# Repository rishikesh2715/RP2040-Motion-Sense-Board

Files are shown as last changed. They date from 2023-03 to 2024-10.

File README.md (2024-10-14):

# AN updated version of this board is available [here](https://github.com/rishikesh2715/RP2040_Motion_Logger)

# RP2040-Motion-Sense-Board

A microcontroller PCB based on the RP2040 MCU from Raspberry Pi with an on-board high-performance IMU, 2S LiPo battery charging circuit, 32 MB quad SPI flash memory, and a bunch of GPIO breakouts.

## Features

- ICM 42688-P IMU
- 2S LiPo battery charging circuit
- 32 MB quad SPI flash memory
- TC2030 debug port
- USB C
- ESD protection circuit
- RGB LED
- Multilple GPIO breakouts
- 1 I2C
- 4 ADC
- 1 UART

## Disclaimer

I have not personally tested this board. If you want to manufacture it, you should carefully go through the design once. Downloading this project and opening it in KiCad and running the ERC or DRC will result in many warnings, but almost all of them are safe to ignore as most of them are courtyard overlapping warnings.

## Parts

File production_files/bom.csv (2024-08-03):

Designator | Footprint | Quantity | Value | LCSC Part #
SW2 | SW_SPST_B3U-1000P | 1 | SW_SPST
Y1 | Crystal_SMD_3225-4Pin_3.2x2.5mm | 1 | 12MHz
J3 | PinSocket_1x20_P2.54mm_Vertical | 1 | Conn_01x20
D1 | D_1206_3216Metric | 1 | D_Schottky_Small
C22 | C_0402_1005Metric | 1 | 100n
C18 | C_0402_1005Metric | 1 | 100n
C30 | C_0402_1005Metric | 1 | 1u
C8 | C_0402_1005Metric | 1 | 100n
C29 | C_0402_1005Metric | 1 | 1u
J1 | JST_PH_S2B-PH-SM4-TB_1x02-1MP_P2.00mm_Horizontal | 1 | JST-PH
C24 | C_0402_1005Metric | 1 | 100n
C27 | C_0402_1005Metric | 1 | 10n
D5 | LED_0603_1608Metric | 1 | Green
Q1 | TSOT-23 | 1 | TP0610L
U4 | ICP-42688-P | 1 | ICM-42688-P
C33 | C_0402_1005Metric | 1 | 1u
C6 | C_0402_1005Metric | 1 | 10p
R10 | R_0603_1608Metric | 1 | 37K4
U3 | W25Q64JVXGIQ_TR | 1 | W25Q32JVZP
R13 | R_0402_1005Metric | 1 | 4k7
R6 | R_0402_1005Metric | 1 | 27R
R5 | R_0402_1005Metric | 1 | 5k1
C11 | C_0402_1005Metric | 1 | 100n
R12 | R_0402_1005Metric | 1 | 4K7
C19 | C_0402_1005Metric | 1 | 100n
J4 | PinHeader_1x14_P2.54mm_Vertical | 1 | Conn_01x14
R3 | R_0402_1005Metric | 1 | 4K7
C7 | C_0402_1005Metric | 1 | 100n
C32 | C_0402_1005Metric | 1 | 1u
FB1 | R_0402_1005Metric | 1 | 480R@100MHz
D7 | LED_SK6805_PLCC4_2.4x2.7mm_P1.3mm | 1 | SK6805
R9 | R_0603_1608Metric | 1 | 118K
R15 | R_0402_1005Metric | 1 | 4K7
C9 | C_0402_1005Metric | 1 | 4u7
C21 | C_0402_1005Metric | 1 | 100n
C14 | C_0402_1005Metric | 1 | 100n
R4 | R_0402_1005Metric | 1 | 5k1
C28 | C_0402_1005Metric | 1 | 1u
D4 | SOT-143 | 1 | PRTR5V0U2X
C10 | C_0402_1005Metric | 1 | 100n
R1 | R_0603_1608Metric | 1 | 10K
R7 | R_0402_1005Metric | 1 | 27R
R16 | R_0402_1005Metric | 1 | 4K7
R11 | R_0402_1005Metric | 1 | 1K
C3 | C_0805_2012Metric | 1 | 10u
C2 | C_0805_2012Metric | 1 | 10u
C1 | C_0805_2012Metric | 1 | 10u
R8 | R_0402_1005Metric | 1 | 5K
U2 | QFN40P700X700X90-57N | 1 | RP2040
D3 | LED_0603_1608Metric | 1 | Green
C23 | C_0402_1005Metric | 1 | 1u
C4 | C_0402_1005Metric | 1 | 10p
C12 | C_0402_1005Metric | 1 | 100n
D6 | LED_0603_1608Metric | 1 | LED
C16 | C_0402_1005Metric | 1 | 100n
C20 | C_0402_1005Metric | 1 | 1u
J5 | JST_SH_SM04B-SRSS-TB_1x04-1MP_P1.00mm_Horizontal | 1 | Conn_01x04
J6 | JST_SH_SM04B-SRSS-TB_1x04-1MP_P1.00mm_Horizontal | 1 | Conn_01x04
D2 | LED_0603_1608Metric | 1 | Orange
C31 | C_0402_1005Metric | 1 | 1u
IC1 | MAX17626ATA+T | 1 | MAX17626ATA+T
C25 | C_0402_1005Metric | 1 | 0.1u
P1 | USB_C_Receptacle_HRO_TYPE-C-31-M-12 | 1 | USB_C_Plug_USB2.0
C26 | C_0603_1608Metric | 1 | 2u2
SW1 | SW_SPST_B3U-1000P | 1 | RESET
R2 | R_0402_1005Metric | 1 | 4K7
C5 | C_0805_2012Metric | 1 | 10u
J2 | Tag-Connect_TC2030-IDC-NL_2x03_P1.27mm_Vertical | 1 | TC2030-IDC-NL
R17 | R_0402_1005Metric | 1 | 4K7
R14 | R_0402_1005Metric | 1 | 4K7
U1 | SOT-23-5 | 1 | MCP73831-2-OT
C13 | C_0402_1005Metric | 1 | 10u
L1 | L_1008_2520Metric | 1 | 1u

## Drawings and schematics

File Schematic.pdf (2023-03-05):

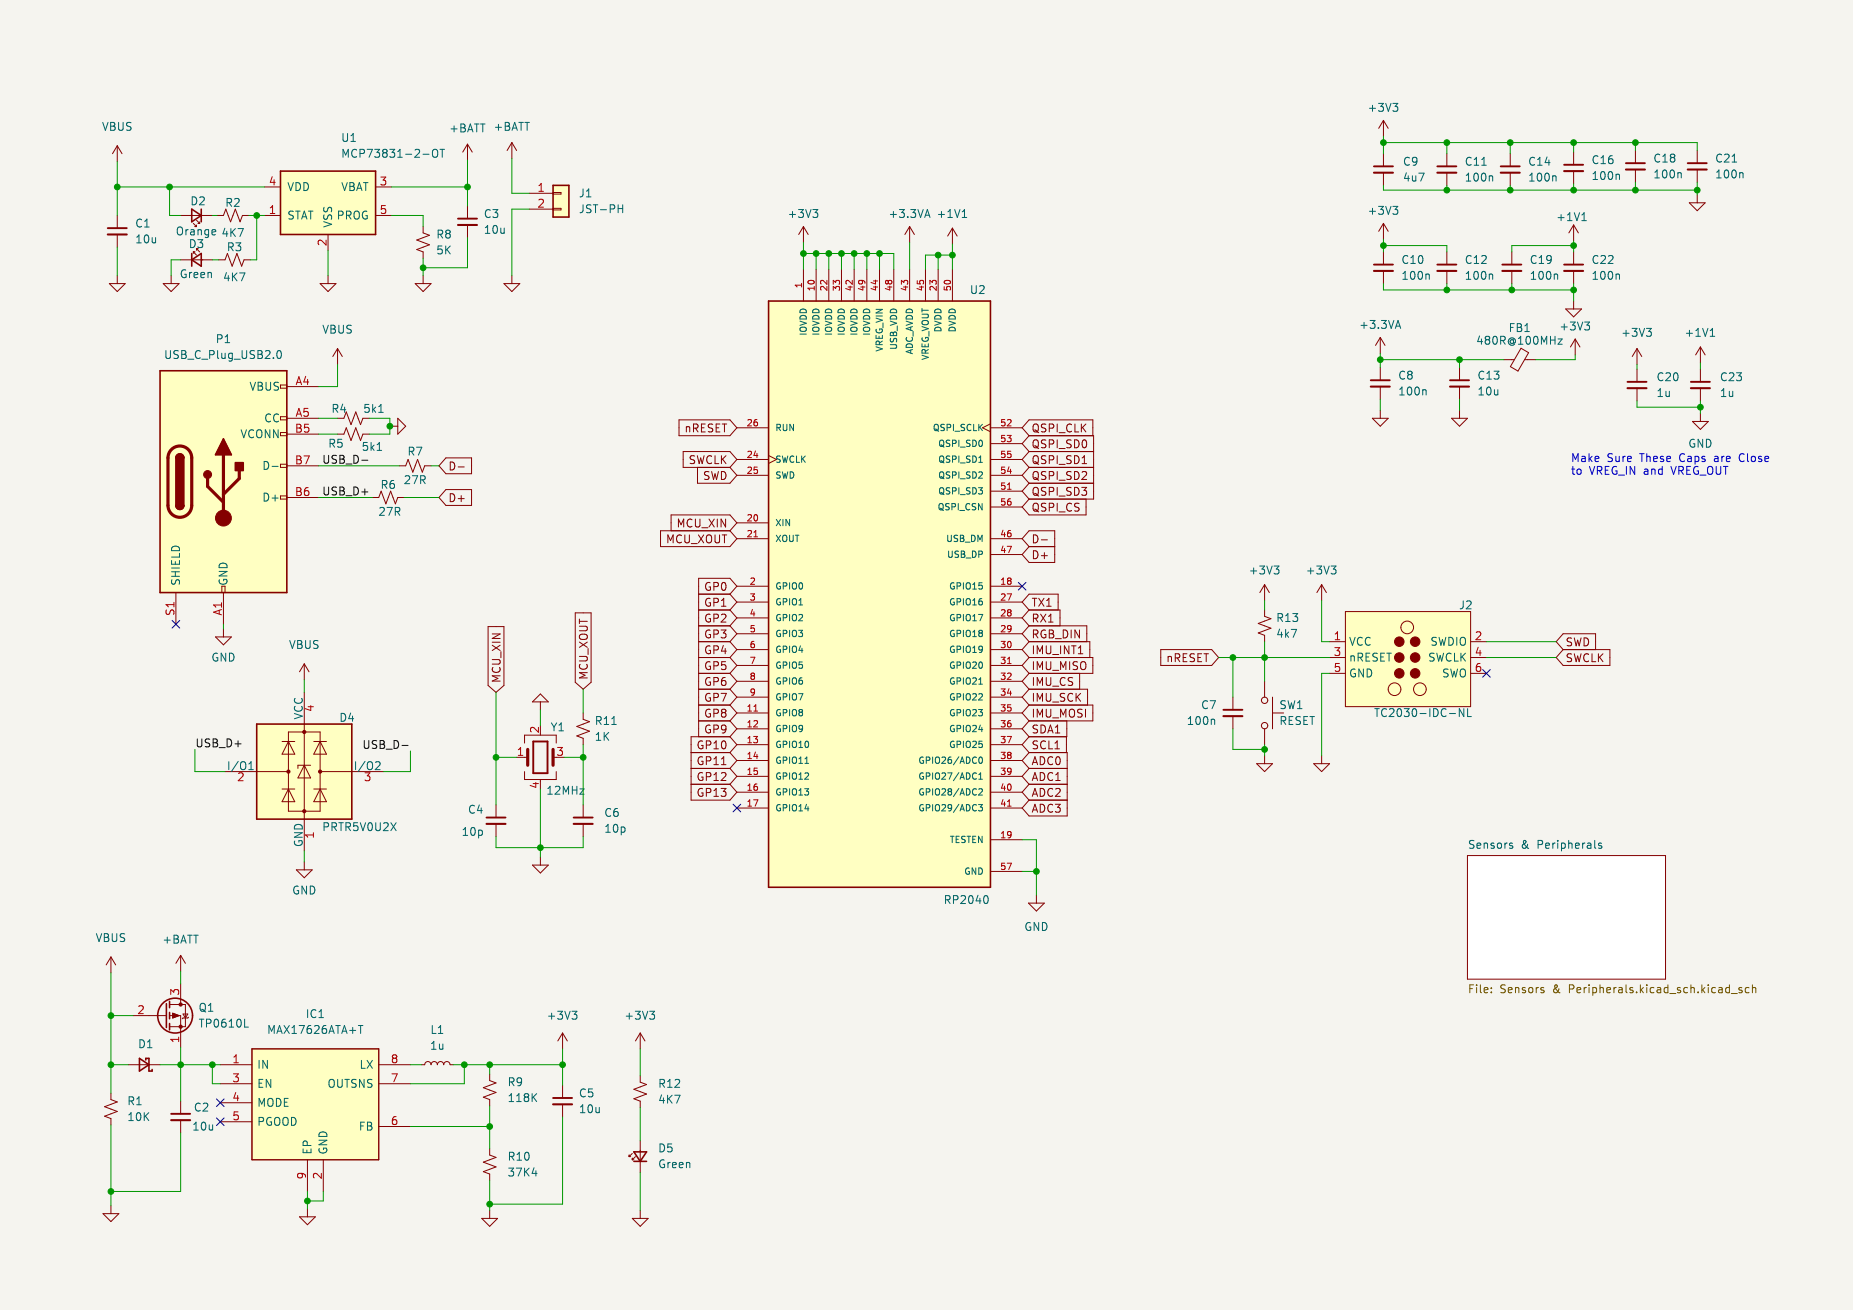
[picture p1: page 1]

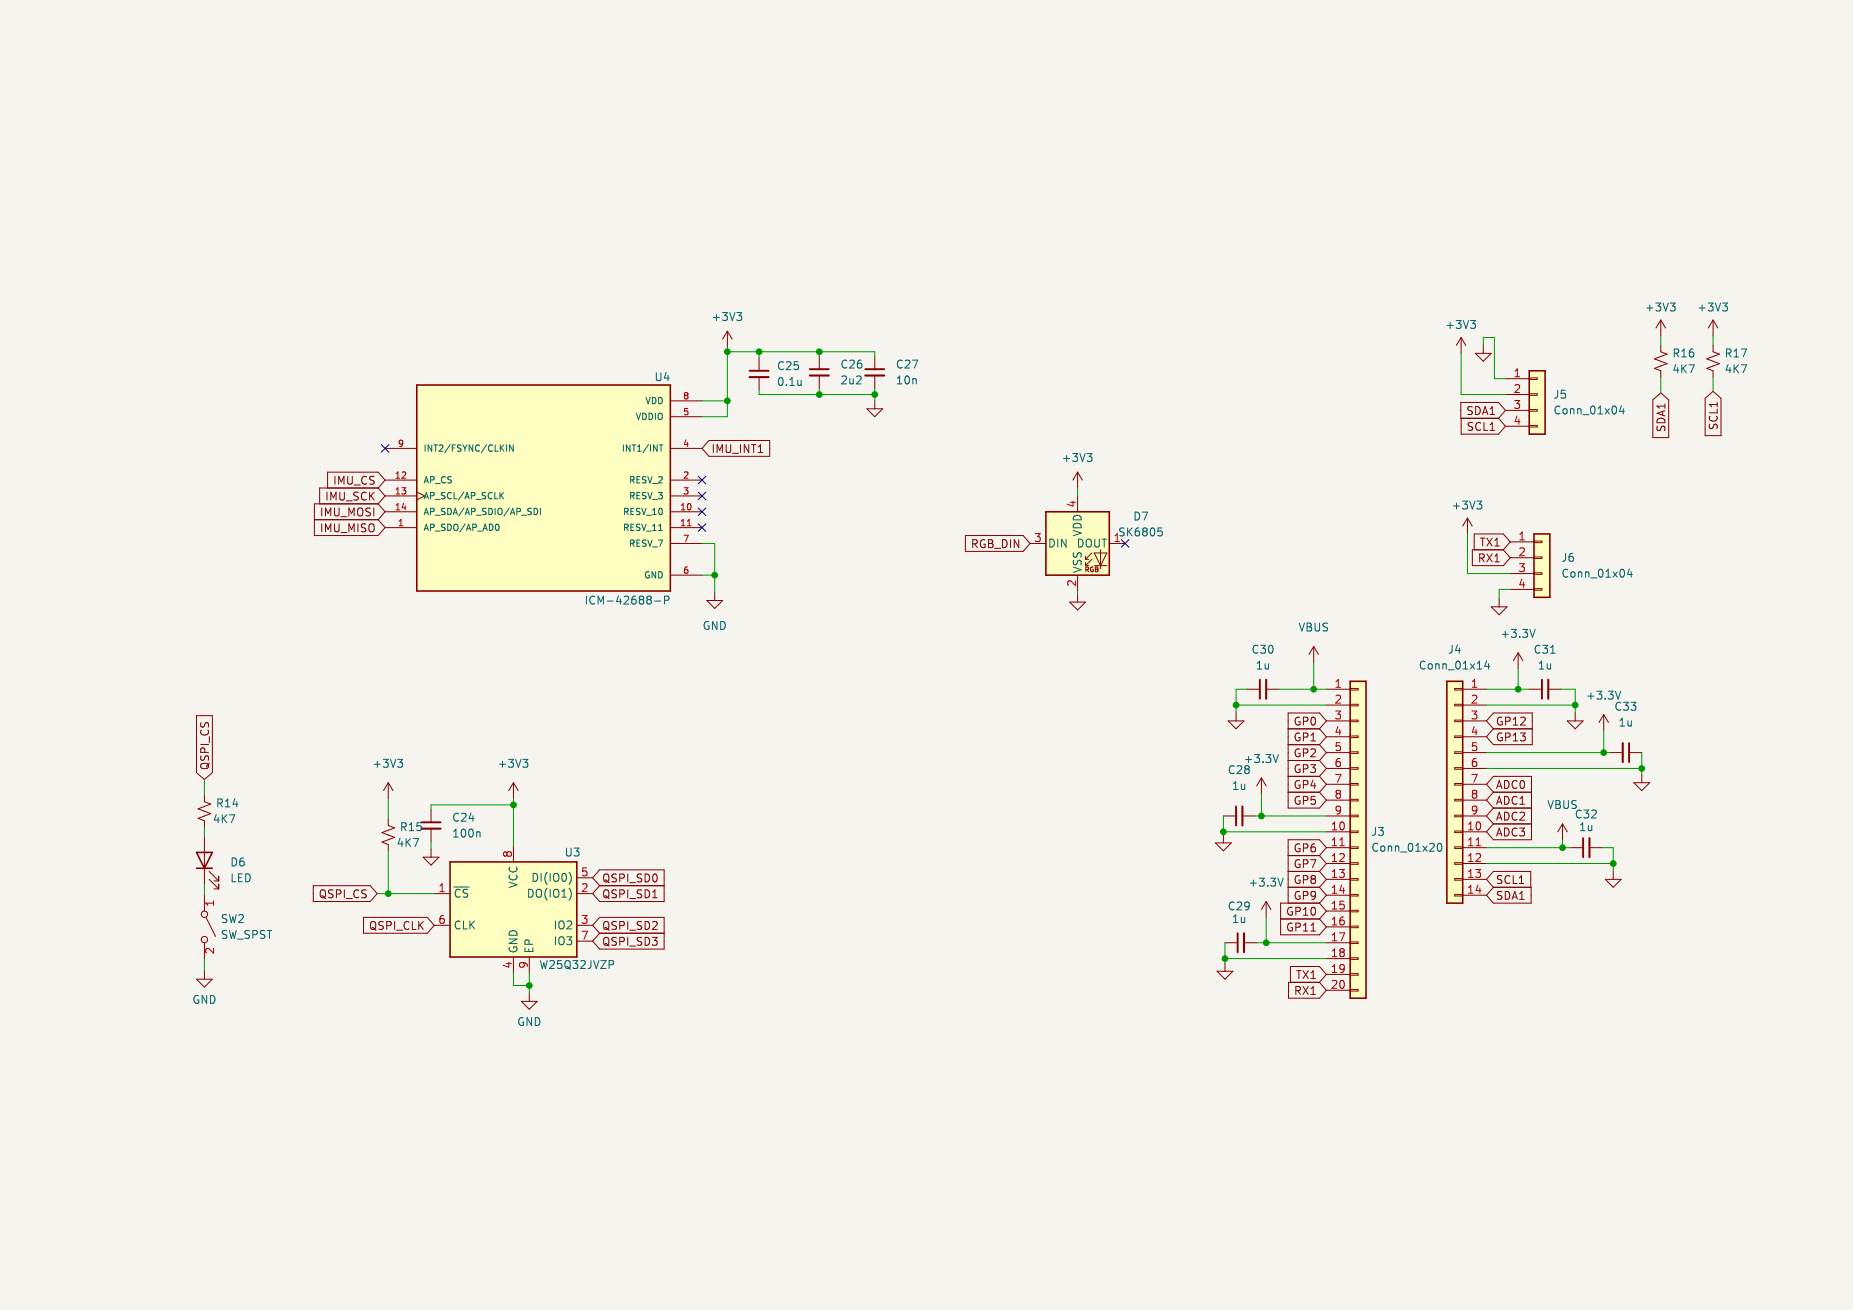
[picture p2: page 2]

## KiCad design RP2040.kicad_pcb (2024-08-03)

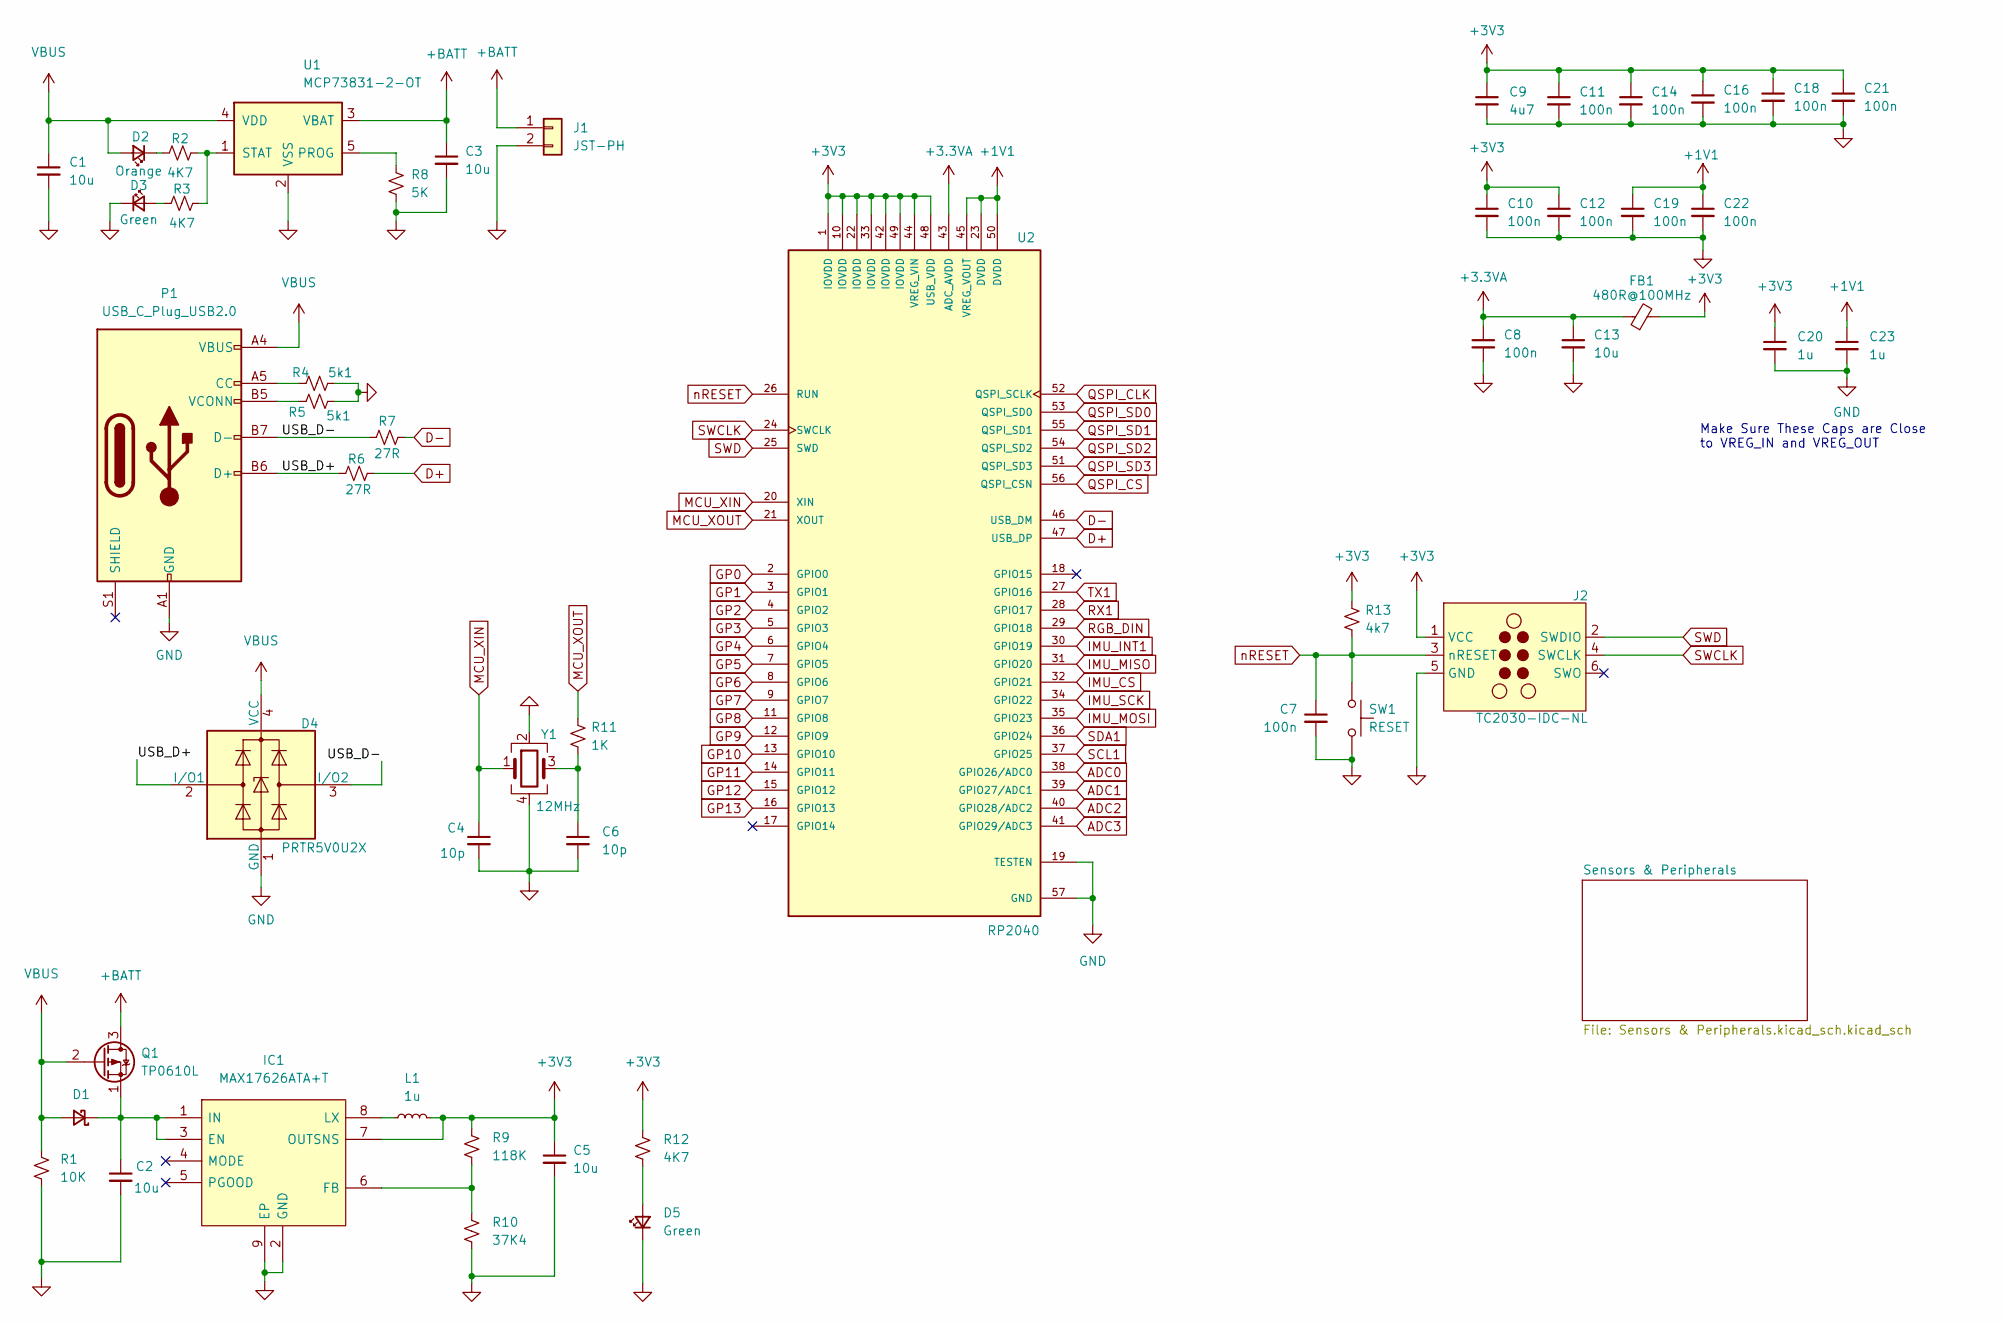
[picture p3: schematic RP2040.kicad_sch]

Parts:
C1, C2, C3, C5: 10u; C_0805_2012Metric
C4, C6: 10p; C_0402_1005Metric
C7, C8, C10, C11, C12, C14, C16, C18, C19, C21, C22: 100n; C_0402_1005Metric
C9: 4u7; C_0402_1005Metric
C13: 10u; C_0402_1005Metric
C20, C23: 1u; C_0402_1005Metric
D1: D_Schottky_Small; D_1206_3216Metric
D2: Orange; LED_0603_1608Metric
D3, D5: Green; LED_0603_1608Metric
D4: PRTR5V0U2X; SOT-143
FB1: 480R@100MHz; R_0402_1005Metric
IC1: MAX17626ATA+T; Mouser Part Number 700-MAX17626ATA+T
J1: JST-PH; JST_PH_S2B-PH-SM4-TB_1x02-1MP_P2.00mm_Horizontal
J2: TC2030-IDC-NL; Tag-Connect_TC2030-IDC-NL_2x03_P1.27mm_Vertical
L1: 1u; L_1008_2520Metric
P1: USB_C_Plug_USB2.0; USB_C_Receptacle_HRO_TYPE-C-31-M-12
Q1: TP0610L; TSOT-23
R1: 10K; R_0603_1608Metric
R2, R3, R12: 4K7; R_0402_1005Metric
R4, R5: 5k1; R_0402_1005Metric
R6, R7: 27R; R_0402_1005Metric
R8: 5K; R_0402_1005Metric
R9: 118K; R_0603_1608Metric
R10: 37K4; R_0603_1608Metric
R11: 1K; R_0402_1005Metric
R13: 4k7; R_0402_1005Metric
SW1: RESET; SW_SPST_B3U-1000P
U1: MCP73831-2-OT; SOT-23-5
U2: RP2040; QFN40P700X700X90-57N; PARTREV 1.6.1
Y1: 12MHz; Crystal_SMD_3225-4Pin_3.2x2.5mm

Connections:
+1V1: C19.1, C22.1, C23.1, U2.23 (DVDD), U2.45 (VREG_VOUT), U2.50 (DVDD)
+3.3VA: C8.1, C13.1, FB1.1, U2.43 (ADC_AVDD)
+3V3: C5.1, C9.1, C10.1, C11.1, C12.1, C14.1, C16.1, C18.1, C20.1, C21.1, FB1.2, IC1.7 (OUTSNS), J2.1 (VCC), L1.2, R9.1, R12.1, R13.1, U2.1 (IOVDD), U2.10 (IOVDD), U2.22 (IOVDD), U2.33 (IOVDD), U2.42 (IOVDD), U2.44 (VREG_VIN), U2.48 (USB_VDD), U2.49 (IOVDD); also elsewhere on the board
+BATT: C3.1, J1.1, Q1.3 (D), U1.3 (VBAT)
/USB_D+: D4.2 (I/O1), P1.B6 (D+), R6.1
/USB_D-: D4.3 (I/O2), P1.B7 (D-), R7.1
ADC0: U2.38 (GPIO26/ADC0); also elsewhere on the board
ADC1: U2.39 (GPIO27/ADC1); also elsewhere on the board
ADC2: U2.40 (GPIO28/ADC2); also elsewhere on the board
ADC3: U2.41 (GPIO29/ADC3); also elsewhere on the board
D+: R6.2, U2.47 (USB_DP)
D-: R7.2, U2.46 (USB_DM)
GND: C1.2, C2.2, C3.2, C4.2, C5.2, C6.2, C7.2, C8.2, C9.2, C10.2, C11.2, C12.2, C13.2, C14.2, C16.2, C18.2, C19.2, C20.2, C21.2, C22.2, C23.2, D3.1 (K), D4.1 (GND), D5.1 (K), IC1.2 (GND), IC1.9 (EP), J1.2, J2.5 (GND), P1.A1 (GND), P1.A12 (GND), P1.B1 (GND), P1.B12 (GND), R1.2, R4.2, R5.2, R8.2, R10.2, SW1.2, U1.2 (VSS), U2.19 (TESTEN), U2.57 (GND), Y1.2, Y1.4; also elsewhere on the board
GP0: U2.2 (GPIO0); also elsewhere on the board
GP1: U2.3 (GPIO1); also elsewhere on the board
GP2: U2.4 (GPIO2); also elsewhere on the board
GP3: U2.5 (GPIO3); also elsewhere on the board
GP4: U2.6 (GPIO4); also elsewhere on the board
GP5: U2.7 (GPIO5); also elsewhere on the board
GP6: U2.8 (GPIO6); also elsewhere on the board
GP7: U2.9 (GPIO7); also elsewhere on the board
GP8: U2.11 (GPIO8); also elsewhere on the board
GP9: U2.12 (GPIO9); also elsewhere on the board
GP10: U2.13 (GPIO10); also elsewhere on the board
GP11: U2.14 (GPIO11); also elsewhere on the board
GP12: U2.15 (GPIO12); also elsewhere on the board
GP13: U2.16 (GPIO13); also elsewhere on the board
IMU_CS: U2.32 (GPIO21); also elsewhere on the board
IMU_INT1: U2.30 (GPIO19); also elsewhere on the board
IMU_MISO: U2.31 (GPIO20); also elsewhere on the board
IMU_MOSI: U2.35 (GPIO23); also elsewhere on the board
IMU_SCK: U2.34 (GPIO22); also elsewhere on the board
MCU_XIN: C4.1, U2.20 (XIN), Y1.1
MCU_XOUT: R11.1, U2.21 (XOUT)
unnamed: C2.1, D1.1 (K), IC1.1 (IN), IC1.3 (EN), Q1.1 (S)
unnamed: C6.1, R11.2, Y1.3
unnamed: D2.1 (K), R2.1
unnamed: D3.2 (A), R3.1
unnamed: D5.2 (A), R12.2
unnamed: IC1.6 (FB), R9.2, R10.1
unnamed: IC1.8 (LX), L1.1
unnamed: P1.A5 (CC), R4.1
unnamed: P1.B5 (VCONN), R5.1
unnamed: R2.2, R3.2, U1.1 (STAT)
unnamed: R8.1, U1.5 (PROG)
QSPI_CLK: U2.52 (QSPI_SCLK); also elsewhere on the board
QSPI_CS: U2.56 (QSPI_CSN); also elsewhere on the board
QSPI_SD0: U2.53 (QSPI_SD0); also elsewhere on the board
QSPI_SD1: U2.55 (QSPI_SD1); also elsewhere on the board
QSPI_SD2: U2.54 (QSPI_SD2); also elsewhere on the board
QSPI_SD3: U2.51 (QSPI_SD3); also elsewhere on the board
RGB_DIN: U2.29 (GPIO18); also elsewhere on the board
RX1: U2.28 (GPIO17); also elsewhere on the board
SCL1: U2.37 (GPIO25); also elsewhere on the board
SDA1: U2.36 (GPIO24); also elsewhere on the board
SWCLK: J2.4 (SWCLK), U2.24 (SWCLK)
SWD: J2.2 (SWDIO), U2.25 (SWD)
TX1: U2.27 (GPIO16); also elsewhere on the board
VBUS: C1.1, D1.2 (A), D2.2 (A), D4.4 (VCC), P1.A4 (VBUS), P1.A9 (VBUS), P1.B4 (VBUS), P1.B9 (VBUS), Q1.2 (G), R1.1, U1.4 (VDD); also elsewhere on the board
nRESET: C7.1, J2.3 (nRESET), R13.2, SW1.1, U2.26 (RUN)

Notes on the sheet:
Make Sure These Caps are Close to VREG_IN and VREG_OUT

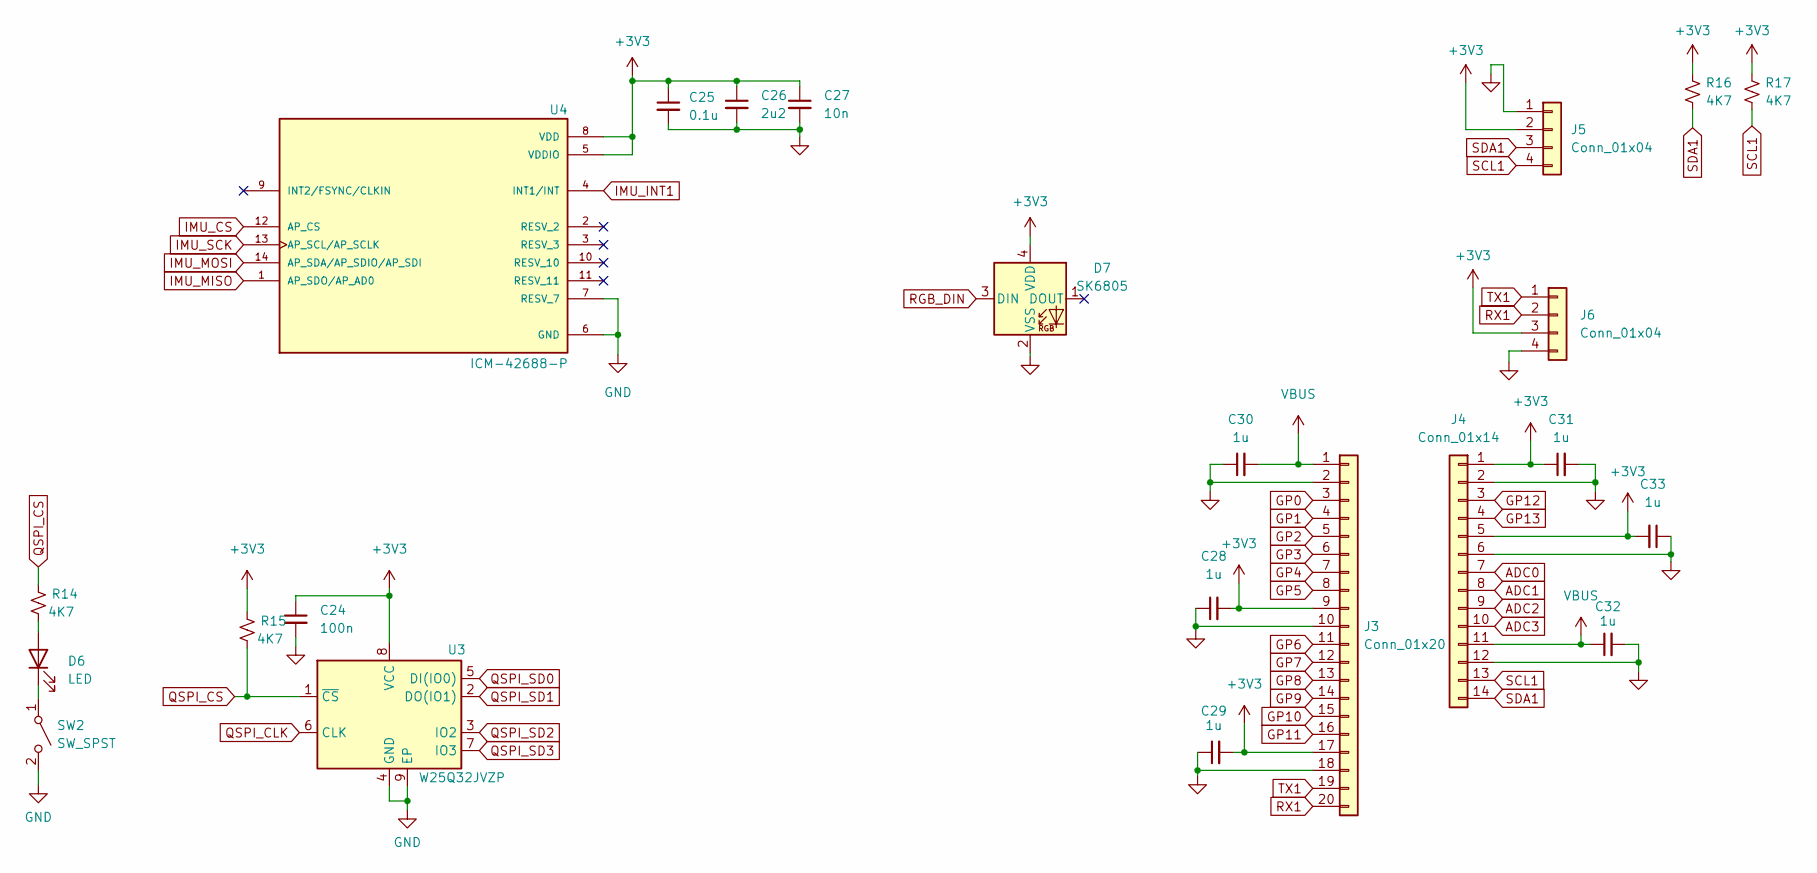
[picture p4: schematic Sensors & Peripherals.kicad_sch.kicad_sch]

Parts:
C24: 100n; C_0402_1005Metric
C25: 0.1u; C_0402_1005Metric
C26: 2u2; C_0603_1608Metric
C27: 10n; C_0402_1005Metric
C28, C29, C30, C31, C32, C33: 1u; C_0402_1005Metric
D6: LED; LED_0603_1608Metric
D7: SK6805; LED_SK6805_PLCC4_2.4x2.7mm_P1.3mm
J3: Conn_01x20; PinSocket_1x20_P2.54mm_Vertical
J4: Conn_01x14; PinHeader_1x14_P2.54mm_Vertical
J5, J6: Conn_01x04; JST_SH_SM04B-SRSS-TB_1x04-1MP_P1.00mm_Horizontal
R14, R15, R16, R17: 4K7; R_0402_1005Metric
SW2: SW_SPST; SW_SPST_B3U-1000P
U3: W25Q32JVZP; W25Q64JVXGIQ_TR
U4: ICM-42688-P; ICP-42688-P; PARTREV 1.2

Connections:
+3V3: C24.1, C25.1, C26.1, C27.1, C28.2, C29.2, C31.1, C33.2, D7.4 (VDD), J3.9, J3.17, J4.1, J4.5, J5.2, J6.3, R15.1, R16.1, R17.1, U3.8 (VCC), U4.5 (VDDIO), U4.8 (VDD); also elsewhere on the board
ADC0: J4.7; also elsewhere on the board
ADC1: J4.8; also elsewhere on the board
ADC2: J4.9; also elsewhere on the board
ADC3: J4.10; also elsewhere on the board
GND: C24.2, C25.2, C26.2, C27.2, C28.1, C29.1, C30.1, C31.2, C32.2, C33.1, D7.2 (VSS), J3.2, J3.10, J3.18, J4.2, J4.6, J4.12, J5.1, J6.4, SW2.2 (B), U3.4 (GND), U3.9 (EP), U4.6 (GND), U4.7 (RESV_7); also elsewhere on the board
GP0: J3.3; also elsewhere on the board
GP1: J3.4; also elsewhere on the board
GP2: J3.5; also elsewhere on the board
GP3: J3.6; also elsewhere on the board
GP4: J3.7; also elsewhere on the board
GP5: J3.8; also elsewhere on the board
GP6: J3.11; also elsewhere on the board
GP7: J3.12; also elsewhere on the board
GP8: J3.13; also elsewhere on the board
GP9: J3.14; also elsewhere on the board
GP10: J3.15; also elsewhere on the board
GP11: J3.16; also elsewhere on the board
GP12: J4.3; also elsewhere on the board
GP13: J4.4; also elsewhere on the board
IMU_CS: U4.12 (AP_CS); also elsewhere on the board
IMU_INT1: U4.4 (INT1/INT); also elsewhere on the board
IMU_MISO: U4.1 (AP_SDO/AP_AD0); also elsewhere on the board
IMU_MOSI: U4.14 (AP_SDA/AP_SDIO/AP_SDI); also elsewhere on the board
IMU_SCK: U4.13 (AP_SCL/AP_SCLK); also elsewhere on the board
unnamed: D6.1 (K), SW2.1 (A)
unnamed: D6.2 (A), R14.2
QSPI_CLK: U3.6 (CLK); also elsewhere on the board
QSPI_CS: R14.1, R15.2, U3.1 (~CS); also elsewhere on the board
QSPI_SD0: U3.5 (DI(IO0)); also elsewhere on the board
QSPI_SD1: U3.2 (DO(IO1)); also elsewhere on the board
QSPI_SD2: U3.3 (IO2); also elsewhere on the board
QSPI_SD3: U3.7 (IO3); also elsewhere on the board
RGB_DIN: D7.3 (DIN); also elsewhere on the board
RX1: J3.20, J6.2; also elsewhere on the board
SCL1: J4.13, J5.4, R17.2; also elsewhere on the board
SDA1: J4.14, J5.3, R16.2; also elsewhere on the board
TX1: J3.19, J6.1; also elsewhere on the board
VBUS: C30.2, C32.1, J3.1, J4.11; also elsewhere on the board

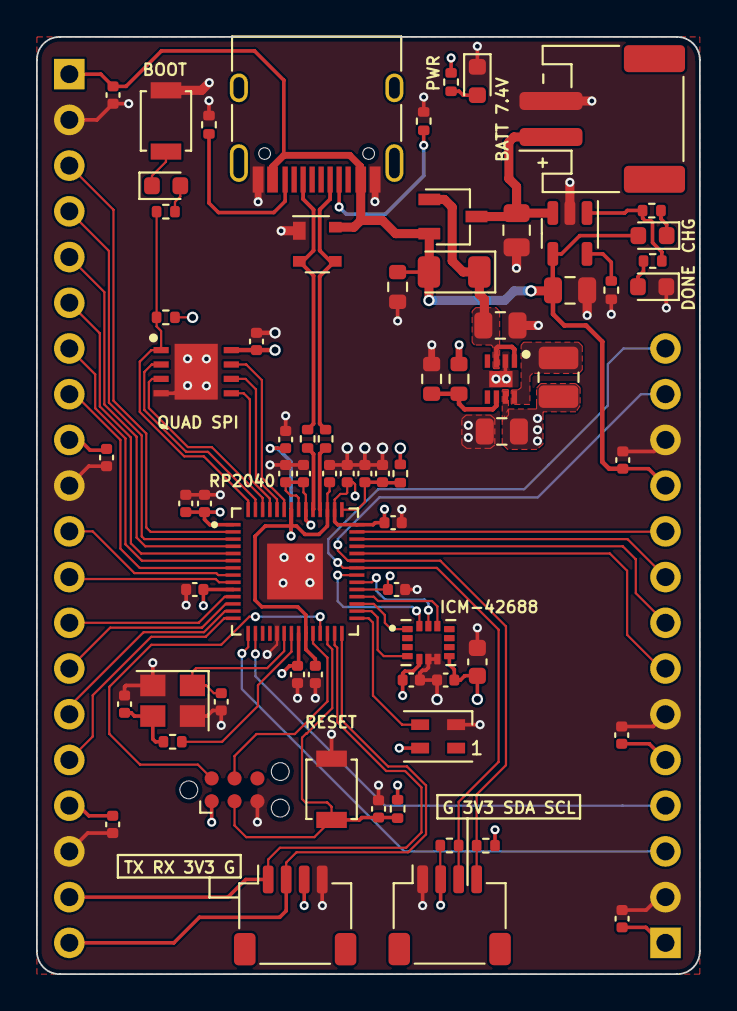
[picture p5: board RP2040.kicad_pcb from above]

Board: 4 copper layers, 36.8 x 52.1 mm, 73 parts (0 on the bottom side), 62 nets.

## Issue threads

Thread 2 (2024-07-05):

Schematic does not open correctly in KiCAD

Arakistech, 2024-07-05:

rishikesh2715, 2024-08-03:
Hi,

I have updated the design files. You should be able to open them now.

Closed 2024-08-03.

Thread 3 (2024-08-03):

My suggestions

Arakistech, 2024-08-03:
Great work!

1- Can you check if your design works with PicoQuake firmware?

https://www.tindie.com/products/plab/picoquake-usb-vibration-sensor/
https://github.com/PLab-SI/PicoQuake

It is also a RP2040 with a ICM-42688 over SPI and USB.

2- Would it be possible to add an optional microSD card slot?

3- Why don´t you think on using a standard Feather form factor for your board? I would be interested in using it as a shield for Stratus board with nRF9161 https://www.crowdsupply.com/conexio/conexio-stratus-pro if your board would have a Feather form factor and could be enabled/disabled via EN pin, it would be great for low power IoT.

rishikesh2715, 2024-08-05:
Yeah, I can include a microSD card slot, but I am pretty sure RP2040 only has one SPI channel so I will have to switch the communication protocol for the IMU to I2C.

And I can design the form factor to be match the Adafruit feather boards.

Closed 2024-08-05.

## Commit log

2024-08-03 Deleted production files from root directory
    [bom.csv, designators.csv, positions.csv]
2024-08-03 updated Production files -- matches JLCPCB format
    [bom.csv, designators.csv, positions.csv]
2024-08-03 updated design files
    [RP2040.kicad_pcb, RP2040.kicad_sch, Sensors & Peripherals.kicad_sch.kicad_sch]
